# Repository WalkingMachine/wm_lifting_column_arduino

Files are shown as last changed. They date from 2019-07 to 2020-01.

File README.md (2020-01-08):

# Description
This repo contains a ROS driver to control a TimMotion TL5 linear actuator. There's a custom board between our driver and the lifting column. 

# Dependencies
* [Encoder.h](https://www.pjrc.com/teensy/td_libs_Encoder.html)

# Topics provided
* Subscriber
    * /column/cmd (std_msgs/Int32)
        * command can range from -255 (down) to 255 (up).
    * /column/set_position (std_msgs/Int32)
        * Allow to set the actual position
* Publisher
    * /column/position (std_msgs/Int32)
        * relative position from the hall sensor

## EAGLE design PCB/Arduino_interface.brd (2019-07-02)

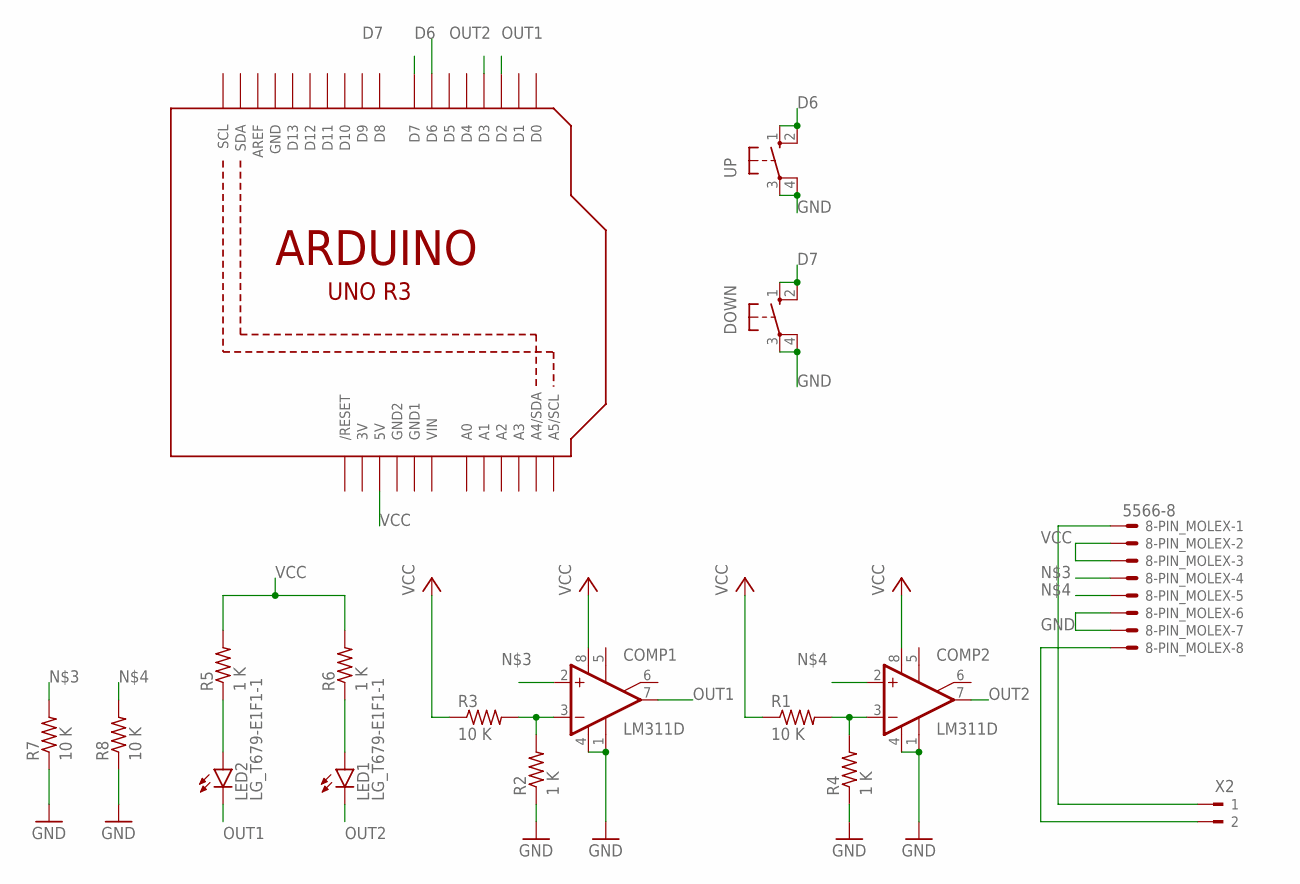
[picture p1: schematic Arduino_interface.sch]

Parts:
8-PIN_MOLEX: 5566-8
COMP1, COMP2: LM311D; SO08; MPN LM311DT
DOWN: 10-XX; B3F-10XX
LED1, LED2: LG_T679-E1F1-1; PLCC2
Q1: ARDUINOR3-NOIOREF-NOTEXT; ARDUINOR3-NOTEXT-NOIOREF
R1, R3: 10 K; M1206; MPN SFR16S0001003FR500
R2, R4, R5, R6: 1 K; M1206; MPN SFR16S0001003FR500
R7, R8: 10 K; M0805
UP: 10-XX; B3F-10XX
X2: 180-2

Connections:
3V: Q1.3V
D6: Q1.D6, UP.1 (S), UP.2 (S1)
D7: DOWN.1 (S), DOWN.2 (S1), Q1.D7
GND: 8-PIN_MOLEX.6, 8-PIN_MOLEX.7, COMP1.1 (GND), COMP1.4 (V-), COMP2.1 (GND), COMP2.4 (V-), DOWN.3, DOWN.4 (P1), Q1.GND, R2.1, R4.1, R7.1, R8.1, UP.3, UP.4 (P1)
GND1: Q1.GND1
GND2: Q1.GND2
unnamed: COMP1.3 (-IN), R2.2, R3.2
unnamed: COMP2.3 (-IN), R1.2, R4.2
unnamed: 8-PIN_MOLEX.4, COMP1.2 (+IN), R7.2
unnamed: 8-PIN_MOLEX.5, COMP2.2 (+IN), R8.2
unnamed: 8-PIN_MOLEX.1, X2.1
unnamed: 8-PIN_MOLEX.8, X2.2
unnamed: LED2.A, R5.1
unnamed: LED1.A, R6.1
OUT1: COMP1.7 (OUT), LED2.C, Q1.D2
OUT2: COMP2.7 (OUT), LED1.C, Q1.D3
VCC: 8-PIN_MOLEX.2, 8-PIN_MOLEX.3, COMP1.8 (V+), COMP2.8 (V+), Q1.5V, R1.1, R3.1, R5.2, R6.2
VIN: Q1.VIN

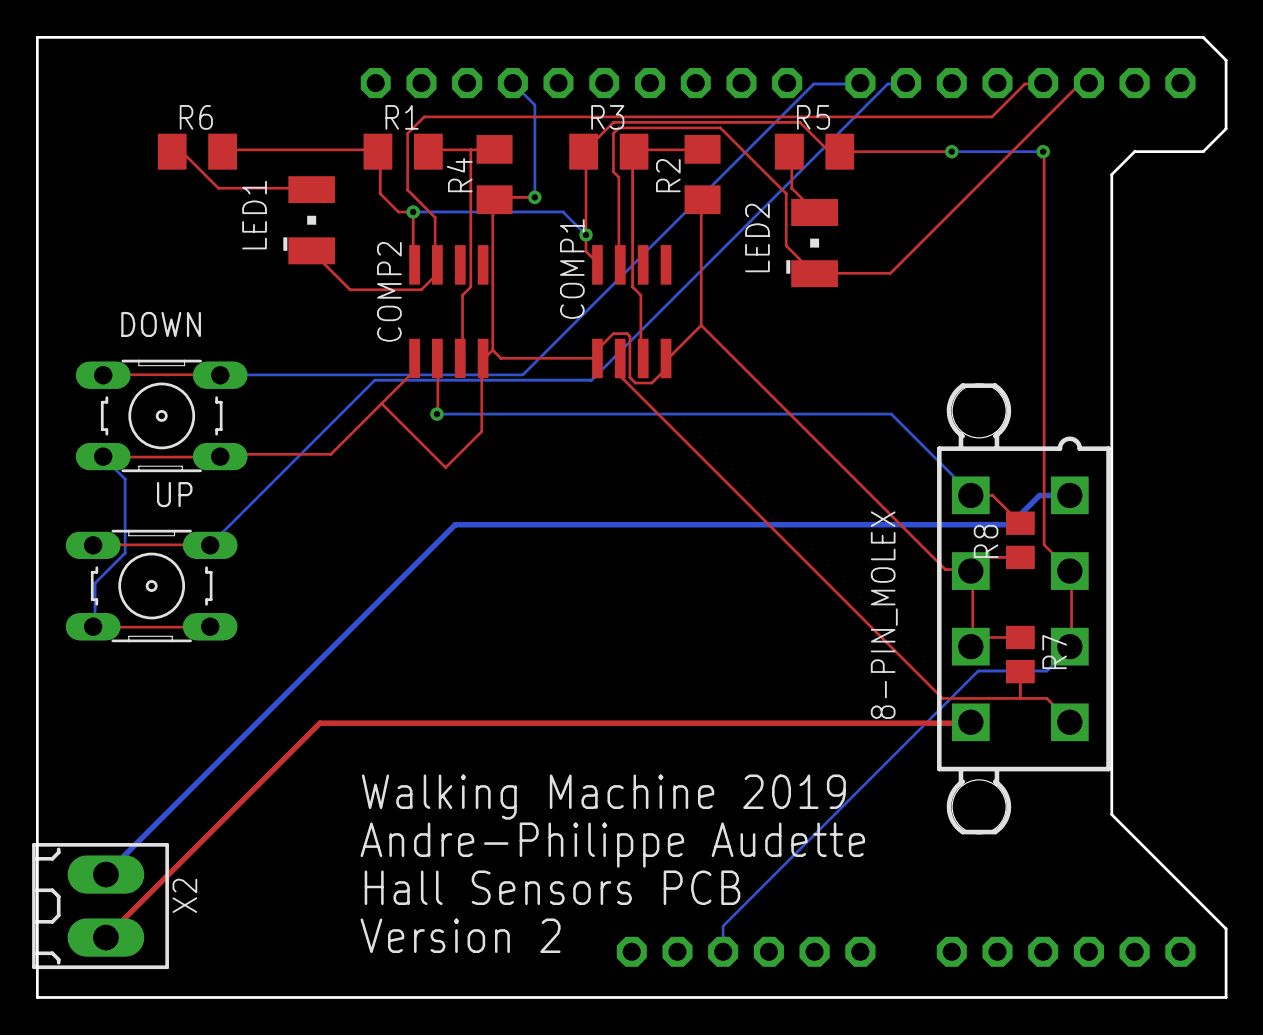
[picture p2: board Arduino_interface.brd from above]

Board: 2 copper layers, 66.0 x 53.3 mm, 17 parts (0 on the bottom side), 14 nets.

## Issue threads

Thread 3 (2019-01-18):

TinyDriverRos

Philippe117, 2019-01-18:
subscribe:
- /column/position std_msgs/Uint32
- /column/goal std_msgs/Float64

publish:
- /column/cmd std_msgs/Int8
- /column/state sensor_msgs/JointState

JeffCousineau, 2019-01-18:
/column/goal ?

Philippe117, 2019-01-18:
wep, la position à ateindre en m

JeffCousineau, 2019-01-18:
Legit :P

Closed 2019-06-14.

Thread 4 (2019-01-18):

Launch file

JeffCousineau, 2019-01-18:
- start rosserial communication with liftin column arduino
- start lifiting column driver

JeffCousineau, 2019-01-18:
#5

Closed 2019-01-18.

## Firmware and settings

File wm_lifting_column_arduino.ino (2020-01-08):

#include <ros.h>
#include <std_msgs/Int32.h>
#include <Encoder.h>
#include <EEPROM.h>

#define UP 1
#define DOWN 0
#define START 1
#define STOP 0

/// Constantvalues
const int ROMADDR = 500;
const int pin_Btn_UP = 6;
const int pin_Btn_DN = 7;
const int pin_DIR = 4;
const int pin_PWM = 5;
const int pin_hallSensorA = 2;
const int pin_hallSensorB = 3;

// Define the EEPROM storage type
union EEPROMSpace {
  long value;
  byte table[4];
};


// Encoder creation
//   Best Performance: both pins have interrupt capability
//   Good Performance: only the first pin has interrupt capability
//   Low Performance:  neither pin has interrupt capability
Encoder myEnc(pin_hallSensorA, pin_hallSensorB);
//   avoid using pins with LEDs attached


// Position encoding variables
EEPROMSpace oldPosition;
long inactivityCounter = 0;
long lastMllis = 0;

// Buttons config
bool oldButtonUPState = false;
bool oldButtonDOWNState = false;

// ROS callbacks
void cmdCallback(const std_msgs::Int32& cmd) {
  // Send commanded speed and direction to the drive
  if(cmd.data  < 0){
    digitalWrite(pin_DIR, DOWN);
  } else if(cmd.data > 0){
    digitalWrite(pin_DIR, UP);
  }
  analogWrite(pin_PWM, abs(cmd.data));
}


void setPosition(const std_msgs::Int32& pos) {
  myEnc.write(pos.data);
}


// ROS objects
ros::NodeHandle nh;
volatile std_msgs::Int32 positionMessage;
ros::Publisher positionPub("column/position", &positionMessage);
ros::Subscriber<std_msgs::Int32> subCmd("/column/cmd", cmdCallback );
ros::Subscriber<std_msgs::Int32> subSetPosition("/column/set_position", setPosition );



// Start function
void setup() {

  Serial.begin(57600);
  nh.initNode();
  nh.advertise(positionPub);
  nh.subscribe(subCmd);
  nh.subscribe(subSetPosition);

  // Configure pins
  pinMode(pin_PWM, OUTPUT);
  pinMode(pin_DIR, OUTPUT);
  digitalWrite(pin_PWM, STOP);
  digitalWrite(pin_DIR, UP);
  pinMode(pin_Btn_UP, INPUT_PULLUP);
  pinMode(pin_Btn_DN, INPUT_PULLUP);

  // Load previous position from EEPROM
  oldPosition.table[0] = EEPROM.read(ROMADDR+0);
  oldPosition.table[1] = EEPROM.read(ROMADDR+1);
  oldPosition.table[2] = EEPROM.read(ROMADDR+2);
  oldPosition.table[3] = EEPROM.read(ROMADDR+3);

  myEnc.write(oldPosition.value);
}


// Loop function
void loop() {

  // Enforce rate
  long currentMilis = millis();
  if(currentMilis - lastMllis > 50){
  
    // Manage override buttons
    if(digitalRead(pin_Btn_UP) == LOW) {
      oldButtonUPState = true;
      digitalWrite(pin_DIR, UP);
      digitalWrite(pin_PWM, START);
    } else if (oldButtonUPState) {
      oldButtonUPState = false;
      digitalWrite(pin_DIR, DOWN);
      digitalWrite(pin_PWM, STOP);
    } else if(digitalRead(pin_Btn_DN) == LOW) {
      oldButtonDOWNState = true;
      digitalWrite(pin_DIR, DOWN);
      digitalWrite(pin_PWM, START);
    } else if (oldButtonDOWNState) {
      oldButtonDOWNState = false;
      digitalWrite(pin_DIR, DOWN);
      digitalWrite(pin_PWM, STOP);
    }


    // Get the latest position
    positionMessage.data = myEnc.read();

    // Check if the collumn is moving and save the position in EEPROM once if not.
    if (positionMessage.data == oldPosition.value){
      inactivityCounter ++;
      if (inactivityCounter == 20){  // Counter to add some tolerance.
        EEPROM.put(ROMADDR+0,oldPosition.table[0]);
        EEPROM.put(ROMADDR+1,oldPosition.table[1]);
        EEPROM.put(ROMADDR+2,oldPosition.table[2]);
        EEPROM.put(ROMADDR+3,oldPosition.table[3]);
      }
    } else {
      inactivityCounter = 0;
    }
    
    // Update ROS
    nh.spinOnce();
    positionPub.publish( &positionMessage );
    lastMllis = currentMilis;
    oldPosition.value = positionMessage.data;
  }
}

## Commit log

2019-01-18 fix un typo de ma part
    [wm_lifting_column_arduino.ino]
2019-01-18 Arduino done, add ros pkg, start ros driver, add launch file
2019-01-20 Fix arduino code and state publisher UInt8->Int8
    [wm_lifting_column_arduino.ino]
2019-01-20 Add brackets
2019-01-23 Fix joint_state topic
2019-03-15 Velocity control + CLeanup
2019-04-08 Change frequency and init bug fix
    [wm_lifting_column_arduino.ino]
2019-05-09 corrige une erreur d'addresse dans la EEPROM
    [wm_lifting_column_arduino.ino]
2019-05-11 Détecte le non-mouvement de la colone pour sauvegarder dans la EEPROM au lieux de regarder la commande
2019-05-16 corrige un problème avec l'ecriture dans la EEPROM en utilisant une union
    [wm_lifting_column_arduino.ino]
2019-05-20 réduit la vitesse de communication
2019-06-14 inverse les polaritées du hall sensor
2019-06-14 Utilise la commande pour déterminer la direction du mouvement Pour contourner le bug de pin disfonctionnelle
    [wm_lifting_column_arduino.ino]
2019-06-18 met les bonnes valeurs pour UP et DOWN
2019-07-02 Ajout des fichiers du PCB de la colonne
    [Arduino_interface.brd, Arduino_interface.sch]
2019-10-27 ajuste les limites et la gestion des limites
2019-10-27 Ajoute une détection des limit switches pour le min et le max pour calibrer automatiquement
2019-11-02 Rewrite the arduino code
2019-11-02 Corrige la sauvegarde de la position dans la EEPROM
    [wm_lifting_column_arduino.ino]
